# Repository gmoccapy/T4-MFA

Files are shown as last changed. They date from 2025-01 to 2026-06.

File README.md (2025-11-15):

T4-MFA is a projekt to customize the Dash Board from an 
Volkswagen T4 Van with a color MFA (Multi Function Diaplay)

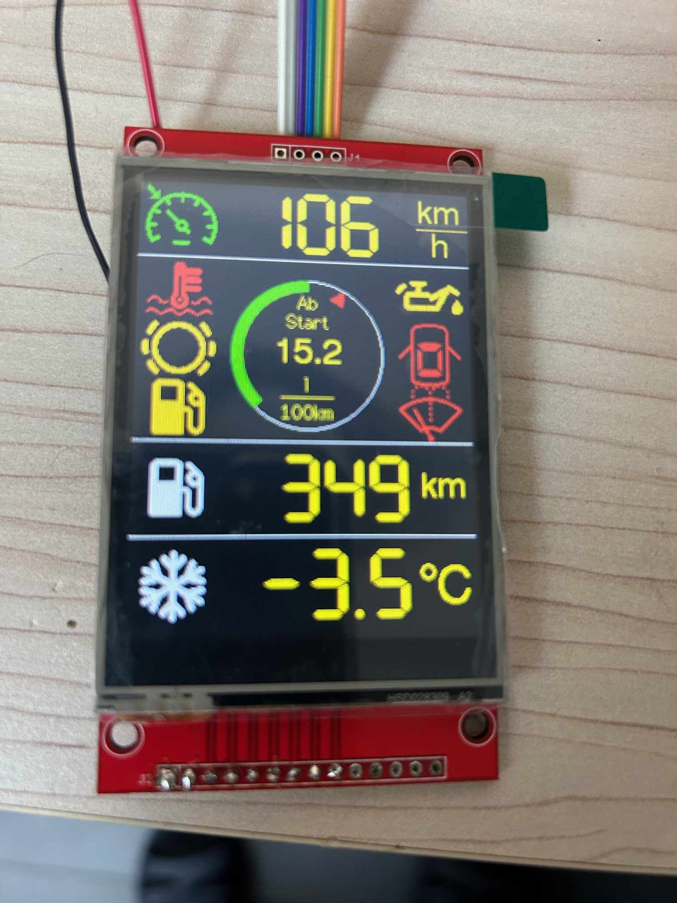
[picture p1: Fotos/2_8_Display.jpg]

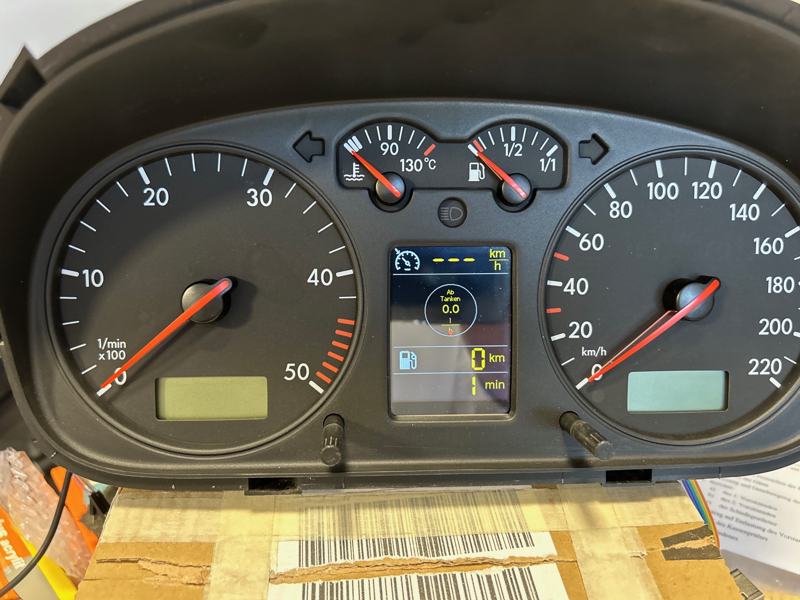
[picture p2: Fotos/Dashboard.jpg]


It is based on a ESP32S-Dev Kit C V4 with 512 kB SRAM and 4 MB Flash
The used display is an 3,5 Inch RPI Display with 480x320 Pixel
The connections from the display need to be modified
The CAN connections are done with a WCMCU-230 Modul (R2 has to be removed)
Power Control is solved with a 12V USB Car Adapter (the mainboard from the adapter has been used)
The connections are done to a self desgned brake out board
Some soldering on the Dash Board Instrument has to be done

The fixture of the display has been solved with a 3d printed part.

Please take care to use ARDUINO IDE 2.XX to programm the ESP
You will need to use following libraries

- ESP32 library 2.0.17 
  Do not use newer one as the newer ones are not supported by the TFT_eSPI library
- TFT_eSPI 2.5.43
- ESP32-TWAI-CAN 1.0.1

Feel free to submit improvements

Electronics and Software Code may be buggy. If you use the code or the hardware mentioned in this repository,
you are responsible to check against you local law. I designed this for my own use. 
I assume no liability for damages resulting from the use of my software or hardware design.

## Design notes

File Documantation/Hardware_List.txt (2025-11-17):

Display:
APKLVSR 3,5" LCD RPi                            (Amazon)        modification of the connectors needed
alternative:
EZ Delivery Waveshare 3,5" TFT Touch Shield     (AZ-Delivery)   not tested jet, advantage backlight control
                                                                3D Holder needs to be modified
Micocontroler:
ESP32 Dev KitC V4 ESP32-WROOM-32 unsoldered     (AZ-Delivery)

Brake Out Board:
see KICAD and Gerber Files

1 x self made board for foto resistors
6 x photo resistor LDR5528 GL5528 (5 mm diameter, max. 2,5 mm hight) (AZ-Delivery) 
6 x pull down resistor 1/4W 10k                                      (AZ-Delivery)

several cable
welding material
4 x Screws M2,5 x 10 

3d Printed parts:
1 x display holder
1 x distance rings

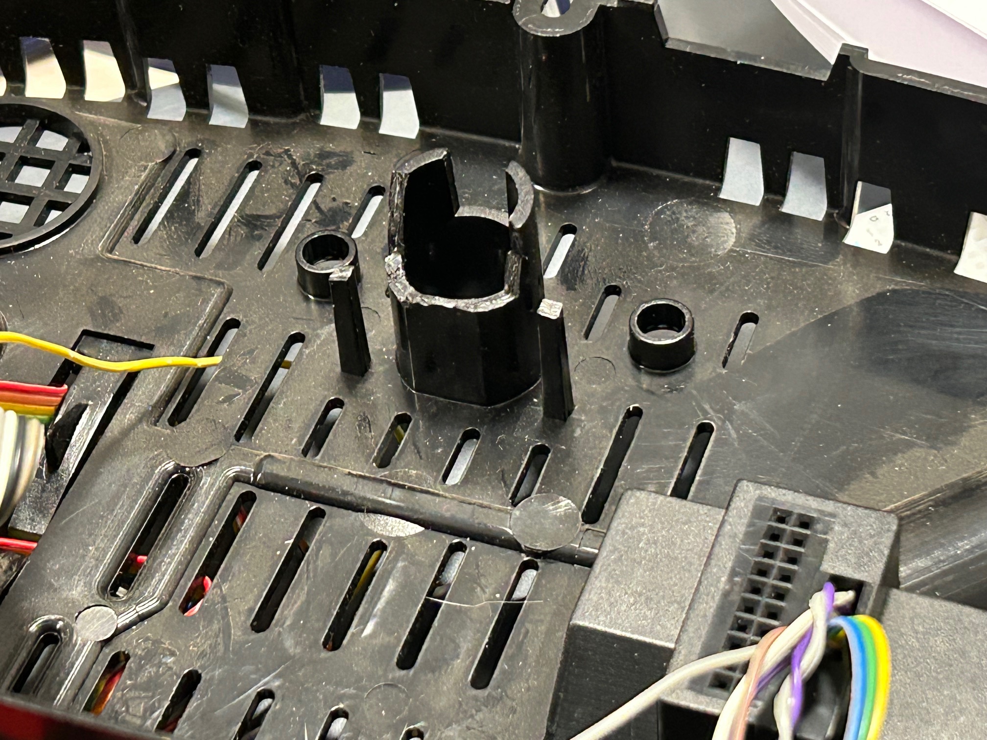
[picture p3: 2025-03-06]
Fotos/Modification_Back_cover_2.jpg

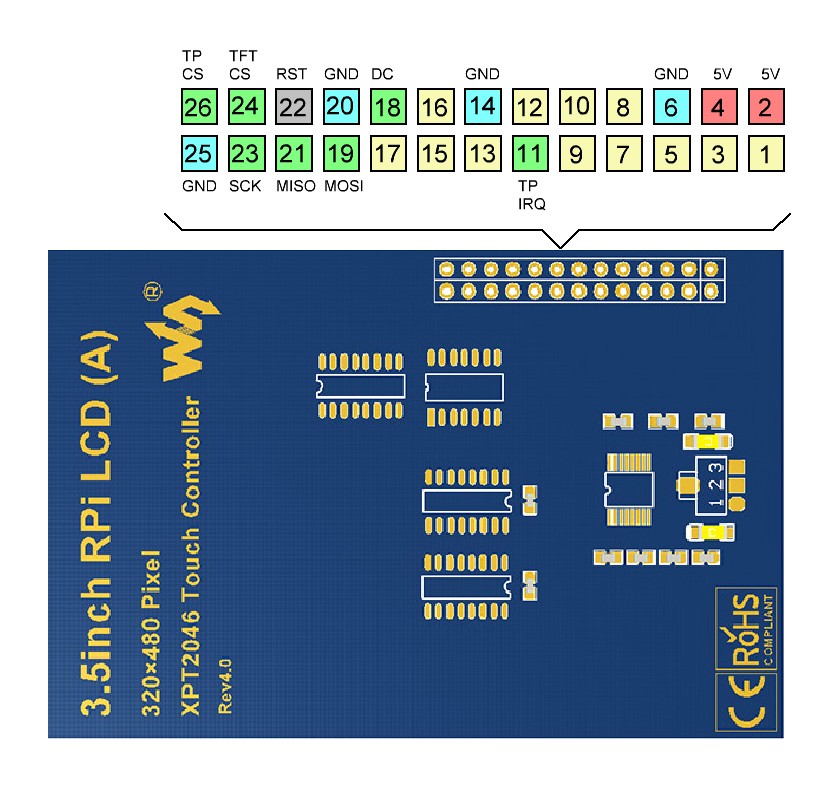
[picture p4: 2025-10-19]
Documantation/RPi 3.5inch Pins.jpg

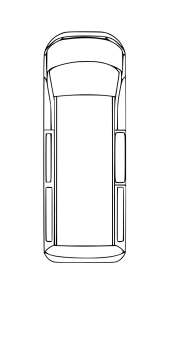
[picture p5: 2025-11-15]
Daniels_Code/Daniel/170x350/T4.png

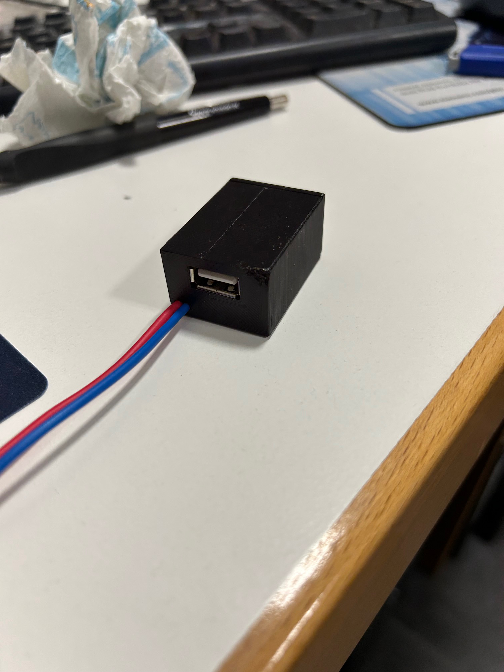
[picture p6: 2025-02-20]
Fotos/Housing_Power_Suply.jpg

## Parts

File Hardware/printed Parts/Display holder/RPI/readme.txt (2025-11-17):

Version 1:
first test, the LED need to be connected through the green and blue connectors,
some evaluation is complicated

Version 2:
Does contain a place to integrate a small board with photo resistors to evaluate the LED state.
I designed it for all 6 LED, even if my KI does only have 5 solderd on the board

Additional board needed, see main hardware folder

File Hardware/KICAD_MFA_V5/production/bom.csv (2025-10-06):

Designator | Footprint | Quantity | Value | LCSC Part #
5V | SolderWire-0.5sqmm_1x01_D0.9mm_OD2.1mm | 1 | TFT_5V
BF1 | SolderWire-0.5sqmm_1x01_D0.9mm_OD2.1mm | 1 | BrakeFluid
BME_280 | PinSocket_1x04_P2.54mm_Vertical | 1 | BME280_conn
BP1 | SolderWire-0.5sqmm_1x01_D0.9mm_OD2.1mm | 1 | BrakePads
C1, C2 | C_0402 | 2 | 100nF | C1525
CAN_H | SolderWire-0.5sqmm_1x01_D0.9mm_OD2.1mm | 1 | Can_H
CAN_L | SolderWire-0.5sqmm_1x01_D0.9mm_OD2.1mm | 1 | Can_L
COOL1 | SolderWire-0.5sqmm_1x01_D0.9mm_OD2.1mm | 1 | Coolant
CS | SolderWire-0.5sqmm_1x01_D0.9mm_OD2.1mm | 1 | TFT_CS
D1, D2 | D_SMB | 2 | S3MB | C18199102
DC | SolderWire-0.5sqmm_1x01_D0.9mm_OD2.1mm | 1 | TFT_DC
GND | SolderWire-0.5sqmm_1x01_D0.9mm_OD2.1mm | 1 | TFT_GND
GPS | PinSocket_1x04_P2.54mm_Vertical | 1 | GPS Modul expansion port
HOLE_1, HOLE_2, HOLE_3, HOLE_4 | MountingHole_3.2mm_M3 | 4 | MountingHole_3.2mm_M3
J1, J2 | PinSocket_1x19_P2.54mm_Vertical | 2 | Conn_01x19_Socket
K15 | SolderWire-0.5sqmm_1x01_D0.9mm_OD2.1mm | 1 | K15
K3 | SolderWire-0.5sqmm_1x01_D0.9mm_OD2.1mm | 1 | K31
K30 | SolderWire-0.5sqmm_1x01_D0.9mm_OD2.1mm | 1 | K30
MC1 | SolderWire-0.5sqmm_1x01_D0.9mm_OD2.1mm | 1 | MotorCap
MEM1 | SolderWire-0.5sqmm_1x01_D0.9mm_OD2.1mm | 1 | Memory
MODE1 | SolderWire-0.5sqmm_1x01_D0.9mm_OD2.1mm | 1 | Mode
MOSI | SolderWire-0.5sqmm_1x01_D0.9mm_OD2.1mm | 1 | TFT_MOSI
OL_LED1 | SolderWire-0.5sqmm_1x01_D0.9mm_OD2.1mm | 1 | O_Lev_LED
OP1 | SolderWire-0.5sqmm_1x01_D0.9mm_OD2.1mm | 1 | OilPresure
OS1 | SolderWire-0.5sqmm_1x01_D0.9mm_OD2.1mm | 1 | oilSensor
Q1 | Q_SOT-23 | 1 | LBSS84LT1G | C8492
Q2 | SOT-363_SC-70-6 | 1 | MMDT3904
R1, R14, R15, R16 | R_0603 | 4 | 10kΩ | C25804
R10, R13, R9 | R_0603x4 | 3 | 10kΩ | C29718
R11, R7, R8 | R_0603x4 | 3 | 4.7kΩ | C1980
R12 | R_0603 | 1 | 4.7kΩ | C23162
R17, R18 | R_0603 | 2 | 4,7k | C25804
R2 | R_0603 | 1 | 220kΩ | C22961
R3, R5 | R_0603 | 2 | 100kΩ | C25803
R4 | R_0603 | 1 | 33kΩ | C4216
R6 | R_0603 | 1 | 220Ω | C22962
RD1 | SolderWire-0.5sqmm_1x01_D0.9mm_OD2.1mm | 1 | Door_R
RESET1 | SolderWire-0.5sqmm_1x01_D0.9mm_OD2.1mm | 1 | Reset
RST | SolderWire-0.5sqmm_1x01_D0.9mm_OD2.1mm | 1 | TFT_RST
SD1 | SolderWire-0.5sqmm_1x01_D0.9mm_OD2.1mm | 1 | Door_S
SLK | SolderWire-0.5sqmm_1x01_D0.9mm_OD2.1mm | 1 | TFT_SLK
TR1 | SolderWire-0.5sqmm_1x01_D0.9mm_OD2.1mm | 1 | Trunk
U1, U2, U3 | DIP-16_W7.62mm | 3 | LTV-847
U4 | DIP-4_L6.5-W4.6-P2.54-LS7.6-BL-1 | 1 | EL817(B)-F
U5 | SOIC-8_L4.9-W3.9-P1.27-LS6.0-BL | 1 | SN65HVD230DR | C12084
U6 | QFN-28-1EP_6x6mm_P0.65mm_EP4.25x4.25mm | 1 | MCP23017_ML
USB_OUT1 | PHOENIX_1729128_2x2,54 | 1 | To USB converter
WW1 | SolderWire-0.5sqmm_1x01_D0.9mm_OD2.1mm | 1 | WhiperWater

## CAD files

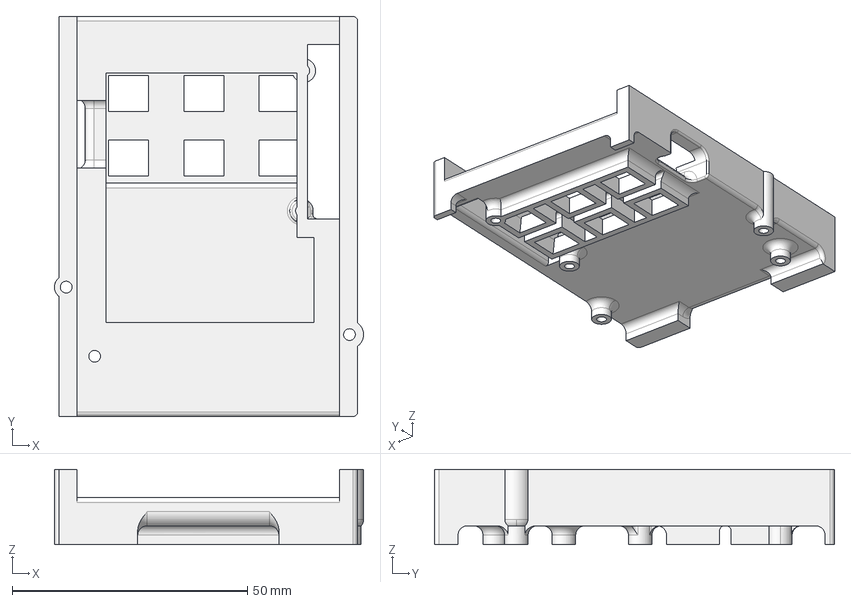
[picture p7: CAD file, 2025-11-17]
Hardware/printed Parts/Display holder/RPI/RPI_480_320_V2.stp
65.7 x 85.0 x 16.0 mm

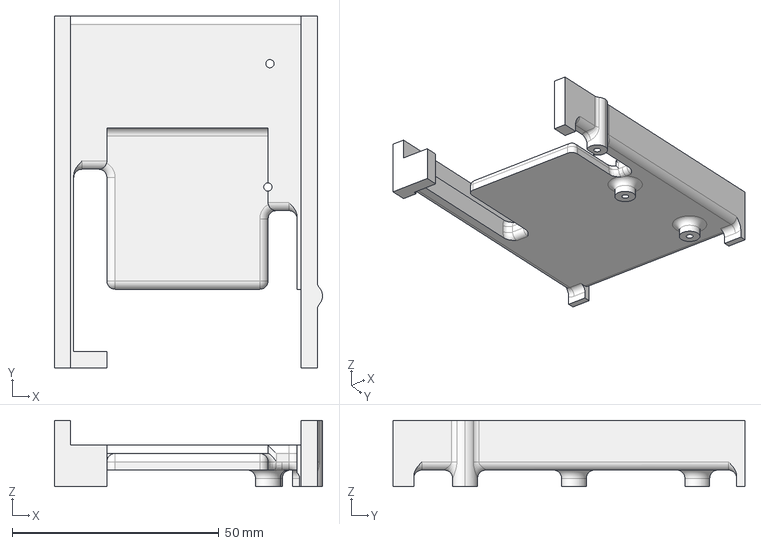
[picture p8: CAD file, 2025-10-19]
Hardware/printed Parts/Display holder/Waveshare/Waveshare_TFT_480x320.stp
64.8 x 85.0 x 16.0 mm

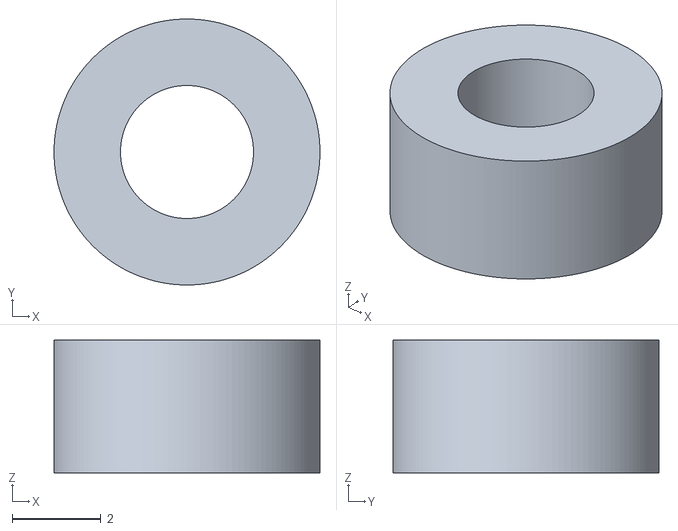
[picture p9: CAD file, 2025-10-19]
Hardware/printed Parts/distance rings/Distanzbuchse 6x3x3.stl
6.00 x 6.00 x 3.00

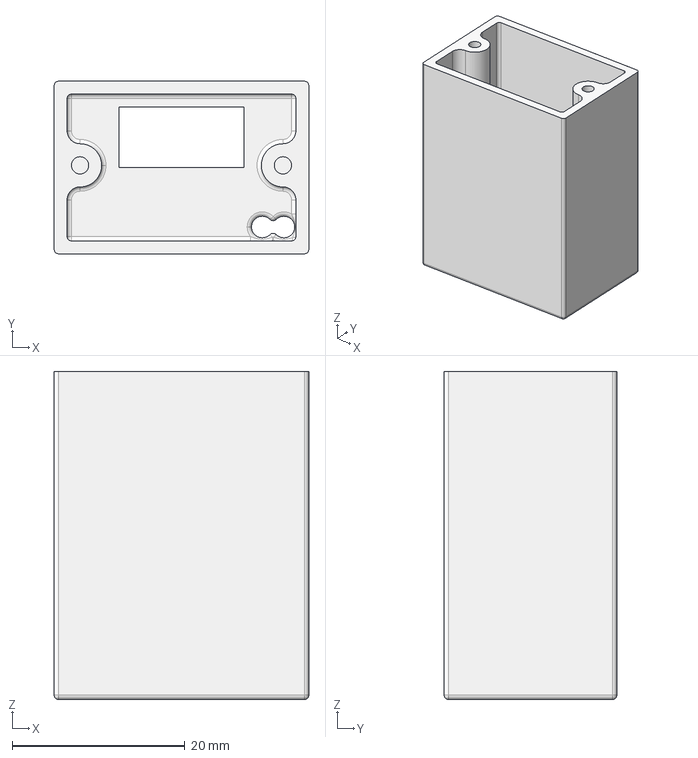
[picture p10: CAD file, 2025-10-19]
Hardware/printed Parts/USB Power Supply Chasis/Ladeplatinengehäuse.stp
29.5 x 20.0 x 38.0 mm

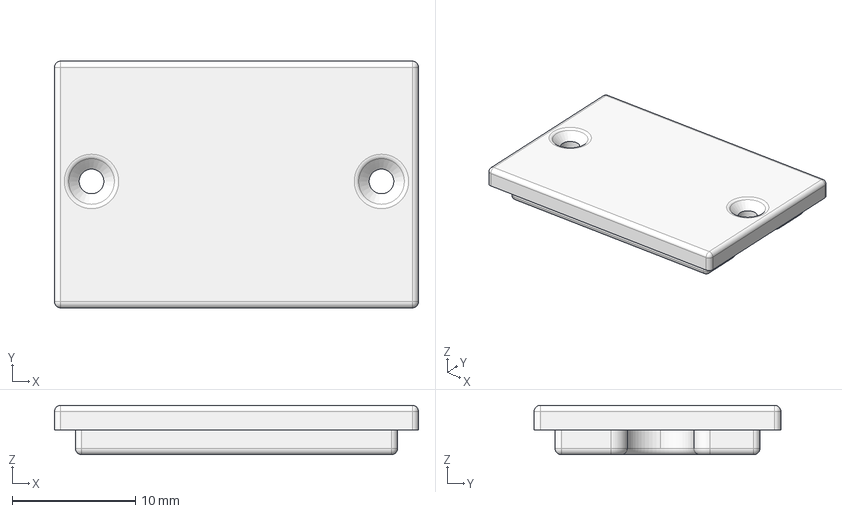
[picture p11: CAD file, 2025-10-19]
Hardware/printed Parts/USB Power Supply Chasis/Gehäusedeckel.stp
29.5 x 20.0 x 4.00 mm

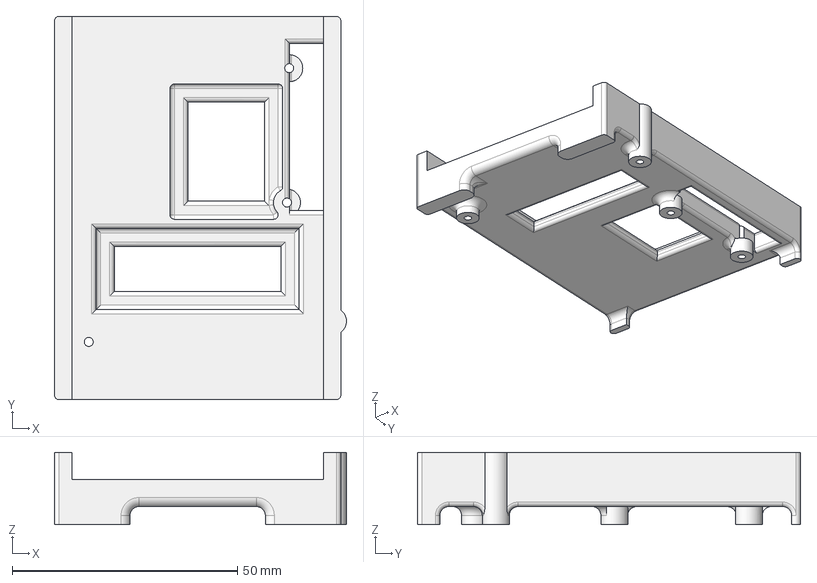
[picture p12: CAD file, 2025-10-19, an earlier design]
Hardware/printed Parts/Display holder/RPI/RPI_480_320.stp
64.8 x 85.0 x 16.0 mm

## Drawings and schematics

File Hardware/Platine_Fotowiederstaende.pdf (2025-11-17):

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

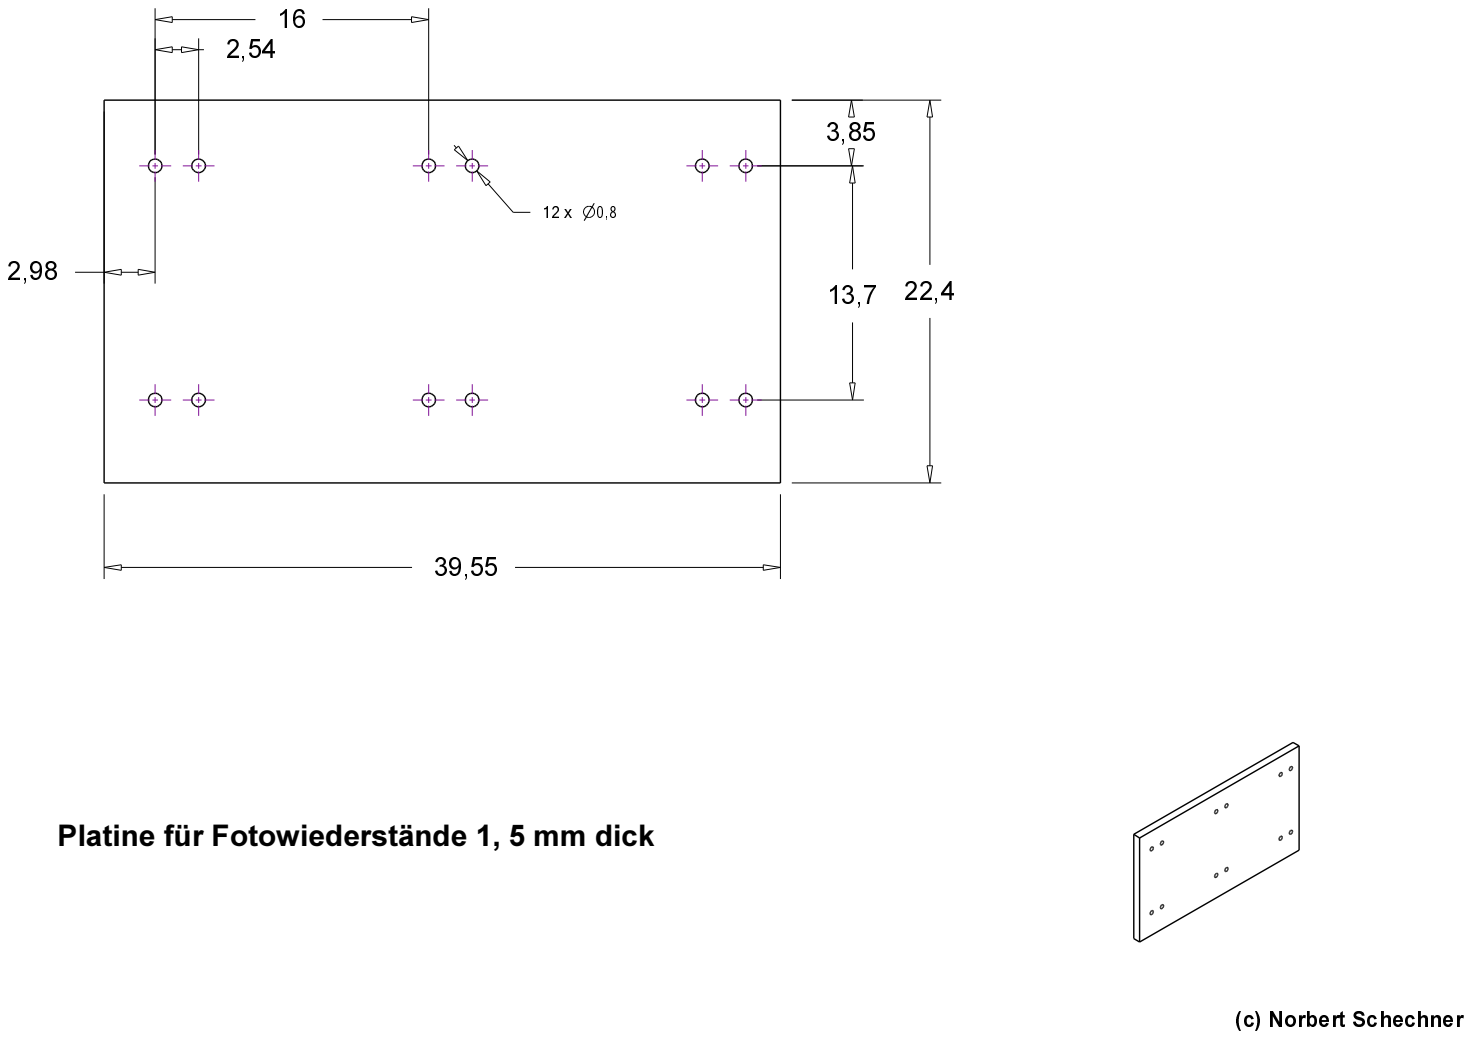
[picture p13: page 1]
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

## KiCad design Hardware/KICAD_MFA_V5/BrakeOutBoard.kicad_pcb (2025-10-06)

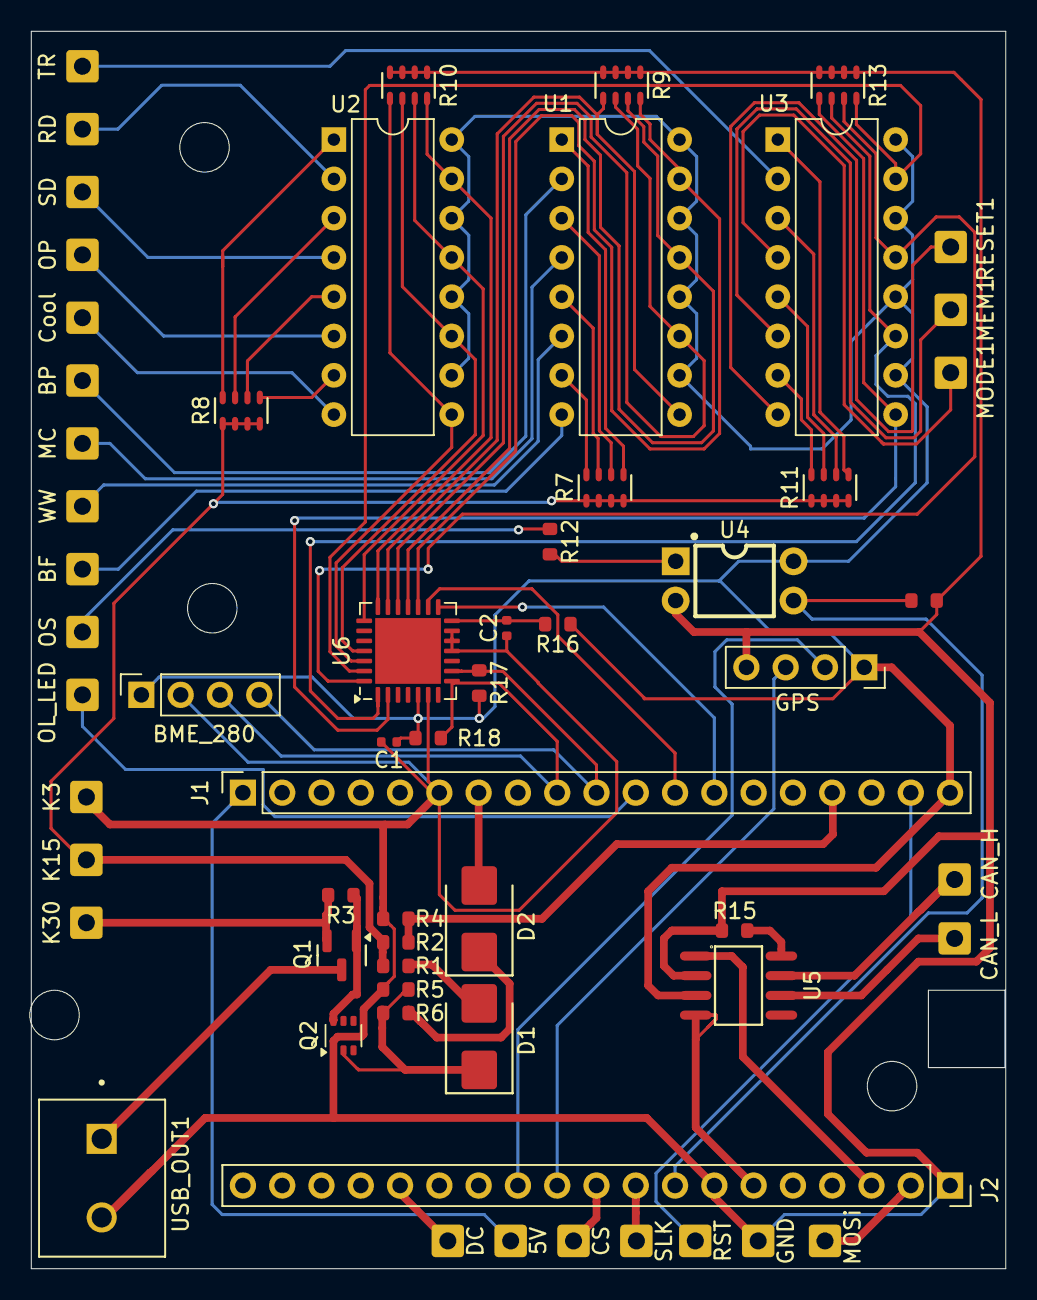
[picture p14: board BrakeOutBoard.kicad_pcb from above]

Board: 2 copper layers, 63.0 x 80.0 mm, 65 parts (0 on the bottom side), 69 nets.

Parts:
5V: TFT_5V; SolderWire-0.5sqmm_1x01_D0.9mm_OD2.1mm
BF: BrakeFluid; SolderWire-0.5sqmm_1x01_D0.9mm_OD2.1mm
BME_280: BME280_conn; PinSocket_1x04_P2.54mm_Vertical
BP: BrakePads; SolderWire-0.5sqmm_1x01_D0.9mm_OD2.1mm
C1, C2: 100nF; C_0402
CAN_H: Can_H; SolderWire-0.5sqmm_1x01_D0.9mm_OD2.1mm
CAN_L: Can_L; SolderWire-0.5sqmm_1x01_D0.9mm_OD2.1mm
CS: TFT_CS; SolderWire-0.5sqmm_1x01_D0.9mm_OD2.1mm
Cool: Coolant; SolderWire-0.5sqmm_1x01_D0.9mm_OD2.1mm
D1, D2: S3MB; D_SMB
DC: TFT_DC; SolderWire-0.5sqmm_1x01_D0.9mm_OD2.1mm
GND: TFT_GND; SolderWire-0.5sqmm_1x01_D0.9mm_OD2.1mm
GPS: GPS Modul expansion port; PinSocket_1x04_P2.54mm_Vertical
Hole_1, Hole_2, Hole_3, Hole_4: MountingHole_3.2mm_M3
J1, J2: Conn_01x19_Socket; PinSocket_1x19_P2.54mm_Vertical
K3: K31; SolderWire-0.5sqmm_1x01_D0.9mm_OD2.1mm
K15: K15; SolderWire-0.5sqmm_1x01_D0.9mm_OD2.1mm
K30: K30; SolderWire-0.5sqmm_1x01_D0.9mm_OD2.1mm
MC: MotorCap; SolderWire-0.5sqmm_1x01_D0.9mm_OD2.1mm
MEM1: Memory; SolderWire-0.5sqmm_1x01_D0.9mm_OD2.1mm
MODE1: Mode; SolderWire-0.5sqmm_1x01_D0.9mm_OD2.1mm
MOSi: TFT_MOSI; SolderWire-0.5sqmm_1x01_D0.9mm_OD2.1mm
OL_LED: O_Lev_LED; SolderWire-0.5sqmm_1x01_D0.9mm_OD2.1mm
OP: OilPresure; SolderWire-0.5sqmm_1x01_D0.9mm_OD2.1mm
OS: oilSensor; SolderWire-0.5sqmm_1x01_D0.9mm_OD2.1mm
Q1: LBSS84LT1G; Q_SOT-23
Q2: MMDT3904; SOT-363_SC-70-6
R1, R14, R15, R16: 10kΩ; R_0603
R2: 220kΩ; R_0603
R3, R5: 100kΩ; R_0603
R4: 33kΩ; R_0603
R6: 220Ω; R_0603
R7, R8, R11: 4.7kΩ; R_0603x4
R9, R10, R13: 10kΩ; R_0603x4
R12: 4.7kΩ; R_0603
R17, R18: 4,7k; R_0603
RD: Door_R; SolderWire-0.5sqmm_1x01_D0.9mm_OD2.1mm
RESET1: Reset; SolderWire-0.5sqmm_1x01_D0.9mm_OD2.1mm
RST: TFT_RST; SolderWire-0.5sqmm_1x01_D0.9mm_OD2.1mm
SD: Door_S; SolderWire-0.5sqmm_1x01_D0.9mm_OD2.1mm
SLK: TFT_SLK; SolderWire-0.5sqmm_1x01_D0.9mm_OD2.1mm
TR: Trunk; SolderWire-0.5sqmm_1x01_D0.9mm_OD2.1mm
U1, U2, U3: LTV-847; DIP-16_W7.62mm
U4: EL817(B)-F; DIP-4_L6.5-W4.6-P2.54-LS7.6-BL-1
U5: SN65HVD230DR; SOIC-8_L4.9-W3.9-P1.27-LS6.0-BL
U6: MCP23017_ML; QFN-28-1EP_6x6mm_P0.65mm_EP4.25x4.25mm
USB_OUT1: To USB converter; PHOENIX_1729128_2x2,54
WW: WhiperWater; SolderWire-0.5sqmm_1x01_D0.9mm_OD2.1mm

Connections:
3,3 V from ESP: BME_280.1, C1.1, GPS.1, J1.19, R16.1, R17.2, R18.2, U1.10, U1.12, U1.14, U1.16, U2.10, U2.12, U2.14, U2.16, U3.10, U3.12, U3.14, U3.16, U4.4, U5.3 (VCC), U6.5 (VDD)
/CAN Modul/CAN_H: CAN_H.1, U5.7 (CANH)
/CAN Modul/CAN_L: CAN_L.1, U5.6 (CANL)
/Latch_Circuit/12 V out: Q1.3 (D), USB_OUT1.1
/Latch_Circuit/K30: K30.1, Q1.2 (S), R3.2
/Optocopler/BrakePads: BP.1, U1.2
/Optocopler/Coolant: Cool.1, U2.8
/Optocopler/DoorRight: RD.1, U2.2
/Optocopler/MemoryButton: MEM1.1, U3.6
/Optocopler/ModeButton: MODE1.1, U3.4
/Optocopler/OilPresure: OP.1, U2.6
/Optocopler/ResetButton: RESET1.1, U3.8
/Optocopler/SlidingDoor: SD.1, U2.4
/Optocopler/Trunk: TR.1, U3.2
/Optocopler/WhiperWater: U1.6, WW.1
CAN Modul CTX: J2.3, U5.1 (D)
CAN Modul RTX: J2.6, U5.4 (R)
GND: BME_280.2, C1.2, C2.1, GND.1, GPS.4, J1.6, J2.1, J2.7, K3.1, Q2.1 (E1), R4.2, R5.1, R9.1, R9.2, R9.3, R9.4, R10.1, R10.2, R10.3, R10.4, R13.1, R13.2, R13.3, R13.4, R14.1, R15.2, U4.2, U5.2 (GND), U6.6 (VSS), U6.11 (A0), U6.12 (A1), U6.13 (A2), USB_OUT1.2
GPIO 16 (PIN 27): GPS.2, J2.12
GPIO 17 (PIN 28): GPS.3, J2.11
GPIO 19 (PIN 31): J2.8, R14.2, U4.3
GPIO 26 (PIN 10): BME_280.4, J1.10, R17.1, U6.9 (SDA)
GPIO 27 (PIN 11): BME_280.3, J1.9, R18.1, U6.8 (SCK)
GPIO 32 (PIN 7): J1.13, U6.15 (INTB)
GPIO 33 (PIN 8): J1.12, U6.16 (INTA)
K15: K15.1, R1.1, R2.1, R7.1, R7.2, R7.3, R7.4, R8.1, R8.2, R8.3, R8.4, R11.1, R11.2, R11.3, R11.4
unnamed: 5V.1, J1.1
unnamed: BF.1, U1.8
unnamed: CS.1, J2.10
unnamed: D1.2, R1.2
unnamed: D2.1, R6.2
unnamed: DC.1, J2.15
unnamed: J1.11, OL_LED.1
unnamed: J1.18, RST.1
unnamed: J2.2, MOSi.1
unnamed: J2.9, SLK.1
unnamed: MC.1, U1.4
unnamed: OS.1, R12.1
unnamed: Q1.1 (G), Q2.6 (C1), R3.1
unnamed: D1.1, Q2.2 (B1), R5.2, R6.1
unnamed: R7.5, U1.1
unnamed: R7.6, U1.3
unnamed: R7.7, U1.5
unnamed: R7.8, U1.7
unnamed: R8.5, U2.7
unnamed: R8.6, U2.5
unnamed: R8.7, U2.3
unnamed: R8.8, U2.1
unnamed: R11.5, U3.1
unnamed: R11.6, U3.3
unnamed: R11.7, U3.5
unnamed: R11.8, U3.7
unnamed: R12.2, U4.1
unnamed: R15.1, U5.8 (RS)
unnamed: C2.2, R16.2, U6.14 (~RESET)
PortExpander GPA0: R9.8, U1.15, U6.17 (GPA0)
PortExpander GPA1: R9.7, U1.13, U6.18 (GPA1)
PortExpander GPA2: R9.6, U1.11, U6.19 (GPA2)
PortExpander GPA3: R9.5, U1.9, U6.20 (GPA3)
PortExpander GPA4: R10.8, U2.15, U6.21 (GPA4)
PortExpander GPA5: R10.7, U2.13, U6.22 (GPA5)
PortExpander GPB0: R10.6, U2.11, U6.25 (GPB0)
PortExpander GPB1: R10.5, U2.9, U6.26 (GPB1)
PortExpander GPB2: R13.8, U3.15, U6.27 (GPB2)
PortExpander GPB3: R13.7, U3.13, U6.28 (GPB3)
PortExpander GPB4: R13.6, U3.11, U6.1 (GPB4)
PortExpander GPB5: R13.5, U3.9, U6.2 (GPB5)
StayOn: D2.2, J1.7
VoltMeasurement: J1.16, R2.2, R4.1

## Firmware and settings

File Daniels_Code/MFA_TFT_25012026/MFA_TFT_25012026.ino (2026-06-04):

/*
  This is a Volkswagen MFA adapted to use CAN Bus from T4
  Based on an ESP32 and RPI TFT Color Display
  Data will be collected by a WCMCU-230 CAN Bus Modul
  
  Please note, that the RPI display has 480 x 320 Pixel, but 
  the visible area will only be: (not modifying the plastik parts of the car) 
  min X_Pos = 10 and max X_Pos = 310
  min Y_Pos = 40 and max Y_Pos = 457
  resuling in a usable width = 300 and height = 417
  if we use a security distance = 4 to avoid mounting differences
  min X_Pos = 14 and max X_Pos = 306
  min Y_Pos = 44 and max Y_Pos = 453
  resuling in a usable width = 292 and height = 409

  Copyright (c) 2024, nieson@web.de and Daniel Braun
  All rights reserved.
*/



//#define with_DIAL   // wenn eingeschaltet,SYM_NA_VISIBLE ausschalten!
#define SYM_NA_VISIBLE // sollen die "ausgeschalteten" LED sichtbar sein? -> Macht nur Sinn, wenn DIAL ausgeschaltet ist.

// #define DEBUG_TFT
// #define DEBUG_CAN
// #define DEBUG_MCP

// include Arduino libraries
#include <TinyGPS++.h>
#include "TFT_eSPI.h"
#include "Free_Fonts.h"
//#include "FreeSansBold24pt7b.h"
#include <ESP32-TWAI-CAN.hpp>
#include <Preferences.h>
#include <Wire.h>
#include <Adafruit_MCP23X17.h>

// include our own files
// Pin definition and settings see pin_setup.h
#include "pin_setup.h"
#include "variables.h"

// include images and symbols
#include "symbols.h"
#include "logo.h"
//#include "T4_Image.h"

// make TFT instance
TFT_eSPI tft = TFT_eSPI();

// make Sprite for the dial (avoid flicker effects)
TFT_eSprite dial = TFT_eSprite(&tft);
TFT_eSprite scale = TFT_eSprite(&tft);
TFT_eSprite needle = TFT_eSprite(&tft);
// make Sprite for the values (avoid flicker effects)
TFT_eSprite box = TFT_eSprite(&tft);
TFT_eSprite left_bar = TFT_eSprite(&tft);
TFT_eSprite right_bar = TFT_eSprite(&tft);
TFT_eSprite compass = TFT_eSprite(&tft);

// set up can system
twai_filter_config_t filter;
CanFrame rxFrame;

// need preferences to store values in NVS (non volatile storage)
Preferences preferences;

// define MCP instance
Adafruit_MCP23X17 mcp;

// Use second kernel to evaluate can messages
TaskHandle_t EvaluateCAN;

// function defination to handle also default values
void drawUnits(int Y_Pos, String upper_line, String lower_line = "");

void setup(void) {

  Serial.begin(115200);

  // start the TFT Display and set orientation
  setup_TFT();

  // Set up can system
  setup_CAN();

  // setup the IO expansion board
  setup_MCP();

  // PIN setup
  pin_setup();

  // load the Data stored in memory
  load_Data();

  // setup GPS functions
  setup_GPS();

  // setup Kline Communication
  //setup_KLine();

  // create some sprites to avoid to much screen drawing
  create_sprites();
 
  // DEBUG:
  Data.page = 0;
  Data.mode = START;


  temp_page = Data.page;
  
  // Create Task on Core 0 to read CAN Messages and not delaying due to TFT Drawing functions
  xTaskCreatePinnedToCore(CAN_Loop, "CAN_Loop", 1000, NULL, 0, &EvaluateCAN, 0);

 // Serial.println("Looping...");
  mcp.clearInterrupts();  // clear

// Initialisiere currentMemory basierend auf aktuellem Memory_Button_state (lese MCP früh)
currentMemory = Memory_Button_state ? 0 : 1;
previousMemoryState = Memory_Button_state;
}

// Main loop running on Core 1 handles all drawing of TFT and IO Stuff
void loop(void) {

// DEBUG
  // Serial.print(time_C_period);
  // Serial.print("\t");
  // Serial.print(C_actual * 100.0 / velocity_actual);
  // Serial.print("\t");
  // Serial.print(C_motor_value);
  // Serial.print("\t");
  // Serial.println(velocity_actual);


  // we are not able to do any hardware stuff on the second task, as it will lead to crashes
  // That's the reason we are doing it in main loop
 
  if (save == true){
    save_Data();
    save = false;
  }

  // initial drawing the screen
  if(start == false){
  // draw the Starting image
    draw_InitPage();
    delay(2000);

    DrawSelected(Data.page);
    start = true;
    //Serial.println("Start"); 
    check_led = true;
    
    // We do an initial check for the mccp state, as we may have unatendet IO's
    check_IO();
  }

  // update time every second
  //if (millis() - lastMillis > 1000){
  //  update_time();
  //  lastMillis = millis();
 // }

// DEBUG : Check LED behavior
  // motor_on = true;
  // petrol = true;
  // light = true;
  // battery = true;
  // brakepads = true;
  // brakesystem = true;
  // washer_fluid = true;
  // oil_pressure = true;
  // door = true;
  // coolant = true;
  // warnings = 511;

  // let the symbol blink, so we do not need a special place for the LED
  // can not be done in check LED, as it will lead to a blinking dial in this case line is 316
  // and should not been done if shutdown timer is running
  
   if (shutdown_timer == 0){
   // if(Data.time_start % 2 != 0){
   //   temp_color = TFT_ORANGE;
   // }
   // else{
   // temp_color = TEXT_COLOR;
  //  }

  if((currentMemory == 0) && (petrol == true) && (Data.page == 0)){
   tft.drawXBitmap(Icon_Pos_Petrol[0], Icon_Pos_Petrol[1], sym_petrol, 50, 50, TFT_ORANGE);  // temp_color verwenden bei gewünschtem blinken
   }
   if ((currentMemory == 0) && (petrol == false) && (Data.page == 0)){ //&& (temp_color == TFT_ORANGE) ){
   tft.drawXBitmap(Icon_Pos_Petrol[0], Icon_Pos_Petrol[1], sym_petrol, 50, 50, SYM_NA_COLOR);
   }

// wird in draw_screen.ino berücksichtigt    prüfen, ob draw_screen oft genug aufgerufen wird
 //Draw Snowflake only if Temp under 4 degrees

}

  update_volt();

  if (check_led == true){
     check_LED();
     check_led = false;
  }

  // to avoid update values for warnings in full page mode
  if (Data.page == temp_page){
    update_values();
  }

  // stay_on == true after we had one time ignition
  // shutdown_timer will be set switching off ignition 
  if ((shutdown_timer != 0) && (millis() > shutdown_timer + shutdown_time)){  
    shutdown_timer = 0;
    digitalWrite(PIN_STAY_ON, 0);
  }

//Mode Button nach IO_handlings verschoben

  if((Reset_Button_pressed != 0) && (millis() > Reset_Button_pressed + 3000)){
    if (Data.mode == PERIOD){
    pending_reset = PERIOD;
    Reset_Button_pressed = 0;
    }
   // if (Data.mode ==REFUEL){
   //   pending_reset = REFUEL;
   //   Reset_Button_pressed = 0;
   // }
  }

uint8_t current_reset = pending_reset;
if (current_reset != NOTHING) {
 reset_Data(current_reset);
  pending_reset = NOTHING;  // reset zurücksetzen
  save = true;
}

  if (!PIN_INT_state){
    check_IO();
    //Serial.println("Checked Interupted PIN"); 
  }

  ////prüfen

  
  if ((PIN_OIL_LEVEL == true) && (oil_level == false)){
    check_LED();
  }
  if ((PIN_OIL_LEVEL == false) && (oil_level == true)){
    check_LED();
  }


// Alle 1000 ms: Zeit + GPS
  if (millis() - lastMillis > 1000) {   
    update_time();     
    update_GPS();
    lastMillis = millis();
  }

//handle_KLine();

if (Memory_Button_state != previousMemoryState) {
   // save_Data();  // Speichere alten Set
  currentMemory = Memory_Button_state ? 0 : 1;
   // load_Data();  // Lade neuen Set
    // Passe maxpage an
    // Korrigiere Data.page, falls zu hoch
   if (Data.page > maxpage[currentMemory]) {
      Data.page = 0;
   }
   temp_page = Data.page;
    DrawSelected(Data.page);  // Redraw 
    previousMemoryState = Memory_Button_state;
   check_led = true;
 }

}



void switch_page(void){
  Data.page += 1;
  if (Data.page > maxpage[currentMemory]){  //DEBUG maxpage is set in variables
    Data.page = 0;
  }
  temp_page = Data.page;
  //Page_Switch_Done = true;
  DrawSelected(Data.page);
 //  Serial.println("Button");
  check_LED();
}


// This loop runs on Core 0, while the main loop runs on Core 1
void CAN_Loop(void *parameter) {
  for(;;) {
    if (ESP32Can.readFrame(rxFrame, 0)) {

      #ifdef DEBUG_CAN
//     Serial.printf("CAN ID: 0x%03X | Data: ", rxFrame.identifier);
      for(int i = 0; i < rxFrame.data_length_code; i++) {
//        Serial.printf("%02X ", rxFrame.data[i]);
      }
//      Serial.println();
      #endif

      //  nur erf. IDs  
      switch(rxFrame.identifier) {
        case 0x280:  // Drehzahl
        case 0x288:  // Geschwindigkeit, Tempomat
        case 0x320:  // Tank, Tür
        case 0x420:  // Außentemp, Öl, Licht
        case 0x480:  // Verbrauch (µl)
        case 0x520:  // Kilometerstand
          evaluate_CAN_messages();
          break;
        default:
          break;  // Ignorieren
      }
    }
    vTaskDelay(1);  // CPU Entlasung
  }
}

void ISR_INT_PIN(void){
  PIN_INT_state = digitalRead(INT_PIN);
}

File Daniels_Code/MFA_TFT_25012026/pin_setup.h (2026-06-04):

// TFT_Setup
// Pin definition and settings see USER_SETUP_ID 11
// #define TFT_MISO 19 not used, commented out in user_setup
// #define TFT_MOSI 23
// #define TFT_SCLK 18
// #define TFT_CS    5  
// #define TFT_DC    2  
// #define TFT_RST  -1  // Set TFT_RST to -1 as display RESET is connected to 
                        // ESP32 board RST, Pin is marked as EN 

// set up GPS
#define GPS_RX_PIN GPIO_NUM_17  
#define GPS_TX_PIN GPIO_NUM_16  
#define GPS_BAUD 9600  // Standard GY-GPS6MV2

// set up can system
// Default for ESP32
#define CAN_RX		GPIO_NUM_21    // Green connector PIN 19
#define CAN_TX		GPIO_NUM_22    // Green connector PIN 20


//#define KLINE_RX_PIN  GPIO_NUM_26
//#define KLINE_TX_PIN  GPIO_NUM_27
//#define KLINE_TX_PIN    GPIO_NUM_13


// MCP Interupt PIN connected to GPIO 33 in this case
#define INT_PIN 33

 // MFA Control PIN according to MCP Laypot
 // pins are numbert according to the following table
 //  0 = mcp.pin_A0
 //  1 = mcp.pin_A1
 //  2 = mcp.pin_A2
 //  3 = mcp.pin_A3
 //  4 = mcp.pin_A4
 //  5 = mcp.pin_A5
 //  6 = mcp.pin_A6
 //  7 = mcp.pin_A7
 //  8 = mcp.pin_B0
 //  9 = mcp.pin_B1
 // 10 = mcp.pin_B2
 // 11 = mcp.pin_B3
 // 12 = mcp.pin_B4
 // 13 = mcp.pin_B5
 // 14 = mcp.pin_B6
 // 15 = mcp.pin_B7

// Brake Pad PIN ; IN Green connector PIN 7
#define PIN_BRAKEPADS 0
// Motor Cap PIN ; IN Green connector PIN 22
#define PIN_MOTOR_CAP 1
// Brake System PIN ; IN Blue connector PIN 29
#define PIN_BRAKESYSTEM 2 
// Wiper Water Warning PIN ; IN Green connector PIN 6
#define PIN_WASHER_FLUID 3

// Door right PIN ; IN   Dieser Eingang wird aktuell zur Überwachung der orange Öl LED benötigt
//#define PIN_R_DOOR 4
// Door Sliding PIN ; IN
#define PIN_S_DOOR 5
// we do not use PIN 6 and 7
// Oil Pressure PIN ; IN
#define PIN_OIL_PRESSURE 8 
// Coolant PIN ; IN
#define PIN_COOLANT 9        
// Trunk PIN ; IN
#define PIN_TRUNK 10

// MODE Switch momentary button
#define PIN_MODE 11
// MEMORY Switch selection switch
#define PIN_MEMORY 12
// RESET Switch momentary button
#define PIN_RESET 13
// we do not use PIN 14 and 15

// we get from Can Bus, so we do not need the following PIN
// Door Left
// petrol warning


// Analog and digital PIN
// Voltage PIN ; IN
#define PIN_Volt 39
// Stay On PIN ; OUT
#define PIN_STAY_ON 12 
// Oil Level PIN ; IN
//#define PIN_OIL_LEVEL 25  // LED Auswertung - 'Änderung nach Pin 4
#define PIN_OIL_LEVEL 4
// Oil Level PWM signal
#define PIN_OIL_PWM GPIO_NUM_19
// OIL LED directly from instrument
#define PIN_OIL_LED 25

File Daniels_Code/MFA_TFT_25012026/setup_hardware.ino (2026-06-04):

void setup_TFT(void){
  // start the TFT Display and set orientation
  tft.begin();
  tft.setRotation(0);
  tft.fillScreen(BACK_COLOR);
  tft.setTextColor(TEXT_COLOR, BACK_COLOR);
}

void setup_CAN(void) {
  twai_general_config_t g_config = TWAI_GENERAL_CONFIG_DEFAULT(CAN_TX, CAN_RX, TWAI_MODE_NORMAL);
  twai_timing_config_t t_config = TWAI_TIMING_CONFIG_500KBITS();
  twai_filter_config_t f_config = TWAI_FILTER_CONFIG_ACCEPT_ALL();

 ESP32Can.begin(
        TWAI_SPEED_500KBPS,     
        CAN_TX,
        CAN_RX,
        0,
        20,
        &f_config,
        &g_config,
        &t_config
      );
  }

void setup_MCP(void){
  Wire.begin(26, 27);

  if (!mcp.begin_I2C(0x20)) {
    tft.fillScreen(TFT_BLACK);
    tft.drawString("Error MCP Start.", 50, 200, FONT4);
  }

}
void pin_setup(void){

  // Stay On PIN ; OUT
  pinMode(PIN_STAY_ON, OUTPUT);

  // OIL LED comes directly from GPIO 25:
  pinMode(PIN_OIL_LED, INPUT);

// TODO: PIN_OIL_PWN as Input from PIN31 from ESP32 coresponds to GPIO 19 
pinMode(PIN_OIL_PWM, INPUT);

  // configure MCP pin that will read INTA/B state
  pinMode(INT_PIN, INPUT);

  // OPTIONAL - call this to override defaults
  // mirror INTA/B so only one wire required
  // active drive so INTA/B will not be floating
  // INTA/B will be signaled with a LOW
  mcp.setupInterrupts(true, false, LOW);

  // configure button pin for input with pull up
  for (byte i = 0; i < 16; i++){
    mcp.pinMode(i, INPUT);
    // enable interrupt on button_pin
    mcp.setupInterruptPin(i, CHANGE);
  }
  attachInterrupt(digitalPinToInterrupt(INT_PIN), ISR_INT_PIN, CHANGE);
}

void setup_GPS(void) {
  GPS_Serial.begin(GPS_BAUD, SERIAL_8N1, GPS_RX_PIN, GPS_TX_PIN);
  _GPS_valid = false; 
  _GPS_time = 0;
  _GPS_direction = 0.0;
  _GPS_speed = 0.0;
  _GPS_last_update = millis();
}

void setup_KLine() {
  // KLine.begin(10400, SERIAL_8N1, KLINE_RX_PIN, KLINE_TX_PIN);
 //  kline_last_init = millis();           // Init in 2–3 Sekunden starten
//  Serial.println("K-Line (UART1) start");
}

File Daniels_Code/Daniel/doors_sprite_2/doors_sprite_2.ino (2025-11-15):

#include "sym_door.h"
#include <TFT_eSPI.h>       
TFT_eSPI    tft = TFT_eSPI();         
TFT_eSprite d_spr = TFT_eSprite(&tft);  

void setup()
{

d_spr.setColorDepth(8); //wictig, sonst nimmt das Sprite zuviel Speicher ein und wird nicht angezeigt
tft.init();


  tft.fillScreen(TFT_BLACK);
}

void loop(void)
{

door_0();
delay(1000);
door_1();
delay(1000);
door_2();
delay(1000);
door_3();
delay (1000);
door_4();
delay(1000);
door_5();
delay(1000);
door_6();
delay(1000);
door_7();
delay(1000);
door_8();
delay(1000);
door_9();
delay(1000);
door_10();
delay(1000);
door_11();
delay(1000);
door_12();
delay(1000);
door_13();
delay(1000);
door_14();
delay(1000);
door_15();
delay(1000); 
door_16();
delay(1000);
door_17();
delay(1000);
door_18();
delay (1000);
door_19();
delay(1000);
door_20();
delay(1000);
door_21();
delay(1000);
door_22();
delay(1000);
door_23();
delay(1000);
door_24();
delay(1000);
door_25();
delay(1000);
door_26();
delay(1000);
door_27();
delay(1000);
door_28();
delay(1000);
door_29();
delay(1000);
door_30();
delay(1000); 
door_31();
delay(1000);
}

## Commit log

2025-01-27 Pin Out Table
    first definition
    [PIN_OUT.ods]
2025-01-27 KiCAD and NGC Files added
    [Power_control.kicad_pcb, Power_control.kicad_sch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]
2025-01-27 New Order of files
    [Power_control.kicad_pcb, Power_control.kicad_sch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]
2025-01-27 added KI Pin Layout
    [Steckerbelegung KI T4.ods]
2025-01-27 moved Files to new folder
    [PIN_OUT.ods]
2025-01-27 renamed file and corrected typo
    [Dash Board Pin Layout T4 with CAN.ods]
2025-01-29 Some changes needed, as button pin are pull up connected
2025-01-29 reorder some files and get the first LED Pin to work PIN 39 can not be used for Oil Level as designed until now, need to find a new solution for that First Fix use PIN 34
    [check_led.ino, pin_setup.h, setup_hardware.ino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]
2025-01-29 used pin twice for oil level and brakepads, so now use washer fluid, as my car does not have a control for that
2025-01-31 Changed Pull up Resistance
    [Power_control.kicad_sch]
2025-02-02 - Reorder the file structure - Changed PIN Connections due to compatibility reasons - Some improvements on time indication, not 2 h 51 min, now 2:52 h makes it easier to calculate and display the val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
    [PIN_OUT.ods]
2025-02-02 Add files via upload
    New layout
    [Power_control.kicad_pcb, Power_control.kicad_sch]
2025-02-03 Still work to do to display the LED ICON correctly
    [MFA_TFT.ino, check_led.ino, dial.ino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]
2025-02-04 Some more debugging on the Warning LED and we have a new ICON for oil temperature
    Still very buggy LED Control, still a way to go
    [MFA_TFT.ino, check_led.ino, draw_screen.ino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]
2025-02-05 Ongoing work on Warning ICON LED handling
2025-02-09 corrected hardware pin out table, mostly cable colors
    [PIN_OUT.ods]
2025-02-09 Updated KiCAD files
2025-02-10 Added Optocopler board
    [Optocopler.kicad_pcb, Optocopler.kicad_sch]
2025-02-10 Add files via upload
    changed denomination of PIN
2025-02-12 Add files via upload
    New Hardware Files
    [BrakeOutBoard.kicad_pcb, BrakeOutBoard.kicad_sch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]
2025-02-12 Delete Hardware/BrakeOutBoard/KICAD/BrakeOutBoard-backups directory
    Backups from PC not needed
2025-02-12 Delete Hardware/Optocopler/KiCAD/Optocopler/Optocopler-backups directory
    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
2025-02-19 New Hardware Layout
    [BrakeOutBoard.kicad_pcb, BrakeOutBoard.kicad_sch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]
2025-02-19 Delete Hardware/BrakeOutBoard/BrakeOutBoard/KICAD/BrakeOutBoard-backups directory
    Only Backups from Computer
2025-02-19 Delete Hardware/BrakeOutBoard/BrakeOutBoard/BrakeOutBoard.pdf
    Old version
2025-02-20 Add files via upload
    Forgot to include connector for Oil Level LED
    [BrakeOutBoard.kicad_pcb, BrakeOutBoard.kicad_sch]
2025-02-20 Added Fotos
    Enclosure for USB Power Supply
2025-03-06 New Hardware layout with: - Port Extender for more IO - I2C Bus extension connector
    [BME_280.kicad_sch, BOM_BrakeOutBoard.csv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]
2025-03-11 Some changes in Hardware needed Code changes Still in process, do not use
    [PIN_OUT.ods]
2025-03-11 New file order
    [BME_280.kicad_sch, BOM_BrakeOutBoard.csv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]
2025-03-11 New Hardware needs new file strukture
    [BOM_BrakeOutBoard.csv]
2025-03-11 Add files via upload
    New Hardware Release 3
    [BOM_BrakeOutBoard.csv]
2025-03-11 Add files via upload
    New Hardware files release 3
    [BOM_BrakeOutBoard.csv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]
2025-03-11 Add files via upload
    Hardware release 1
    [BOM_BrakeOutBoard.csv, BrakeOutBoard.kicad_pcb, BrakeOutBoard.kicad_sch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]
2025-03-11 Add files via upload
    Board didn#t fit, now it is 1 mm lower
    [BrakeOutBoard.kicad_pcb]
2025-03-11 Add files via upload
    Board is now 1 mm lower, because it did not fit
    [BrakeOutBoard-B_Cu.gbl, BrakeOutBoard-B_Mask.gbs, BrakeOutBoard-B_Paste.gbp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]
2025-09-30 Because of errors in hardware, deleted hardware design
    [BME_280.kicad_sch, BOM_BrakeOutBoard.csv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]
2025-09-30 removed unneeded variables as LED Control will be done over IO_handling
2025-09-30 Updated batterie LED handling
2025-10-06 Ne IO Handling after hardware correction
    [IO_handling.ino]
2025-10-06 New Hardware design, due to wrong connections on Optocopler part
    [BME_280.kicad_sch, BrakeOutBoard.kicad_pcb, BrakeOutBoard.kicad_sch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]
2025-10-06 Playing with LED handling
2025-10-09 Still working on Warning LED stuff
2025-10-10 LED Stuff first working layout, but.. - I want to separate warnings and alerts - Warnings show them only for certain time - alerts need to be placed big and stay for ever - I miss some icons for door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
2025-10-10 More work on LED indications
    - Batterie is OK
    - Voltage bar will blink
    - all other LED can be displayed
    - no LED for door_r, sliding_d, motor_cap and trunk
2025-10-10 Mode button will now change modes - From Start - Since Refuel - Long period
2025-10-10 RESET Switch will reset the displayed Data RESET Button must be pressed 3 Seconds to reset the data
    [IO_handling.ino, MFA_TFT.ino, load_save.ino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]
2025-10-10 Changed Mode button handling to use software debounce
2025-10-14 Some reordering in PIN Setup - need to get LED check working, if an PIN is high, on power up, the display is not set correctly
    [IO_handling.ino, MFA_TFT.ino, check_led.ino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]
2025-10-19 added new filed for printed parts and reordered file system a little bit
    [Dash Board Pin Layout T4 with CAN.ods, Gehäusedeckel.stp, Ladeplatinengehäuse.stp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]
2025-10-19 added distance rings
    [Distanzbuchse 6x3x3.stl]
2025-10-29 - Added Daniel to Copyright - changed logic from brake pads - commented some print statements
2025-10-31 included oil level LED
2025-11-13 Included LED Level LED and all DEBUG Statements can now be disabled changing the corresponding line in MFA_TFT.ino
2025-11-15 Added some DEBUG Statements and Shutdown Time is now a defined number so it can be changed easy.
    [BrakeOutBoard.kicad_pcb]
2025-11-15 Solved BUG in evaluate can messages, setting reset = DEPOSIT but reset was an boolean, in this case it worked, but in resetData there was no check for the mode, just deleting the data of the actual m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
    [MFA_TFT.ino, variables.h]
2025-11-17 Added second design for the RPI Display holder with integrated place for Foto Resistors olaced over the LED
    [RPI_480_320_V2.stp]
2026-06-04 Add files via upload
    Additional photos showing the mount situation of the 3,5" RPI Display
2026-06-04 Added the newest code from Daniel
    First test to add k-line reading,
    Not working jet.
    GPS working
    [IO_handling.ino, MFA_TFT_17012026_2.ino, check_led.ino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]
2026-06-04 New code from Daniel
    Added a switch to supress dial, keep Display more clear or classic design
    K-Line still not working
    Double Check your oil control led if you use this code.
    [IO_handling.ino, MFA_TFT_25012026.ino, check_led.ino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]
